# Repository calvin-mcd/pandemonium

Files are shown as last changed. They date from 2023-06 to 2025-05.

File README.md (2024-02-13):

# Pandemonium
 
Pandemonium is an alpha staggered ISO pcb with KLE by HaiZeus. It uses an [XIAO nRF52840](https://www.seeedstudio.com/Seeed-XIAO-BLE-nRF52840-p-5201.html) for bluetooth support. The desgin for that is based on [NoahK#1290's](https://kiserdesigns.bigcartel.com/) [Asymptote](https://github.com/KiserDesigns/Asymptote). For a build guide you can mostly refer to the steps from the [Asymptote Guide](https://github.com/KiserDesigns/Asymptote#asymptote-build-guide). Just take extra care with the right orientation of the diodes, as these change quite a bit on this pcb design. The battery cutout is 54mm x 14mm (max width for batteries used is 14mm).

## Layout

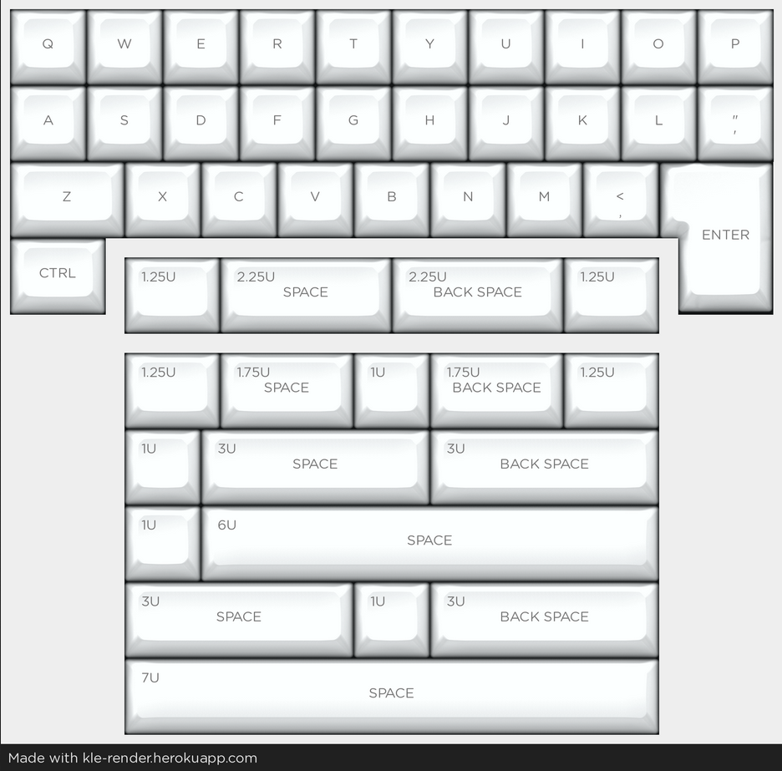
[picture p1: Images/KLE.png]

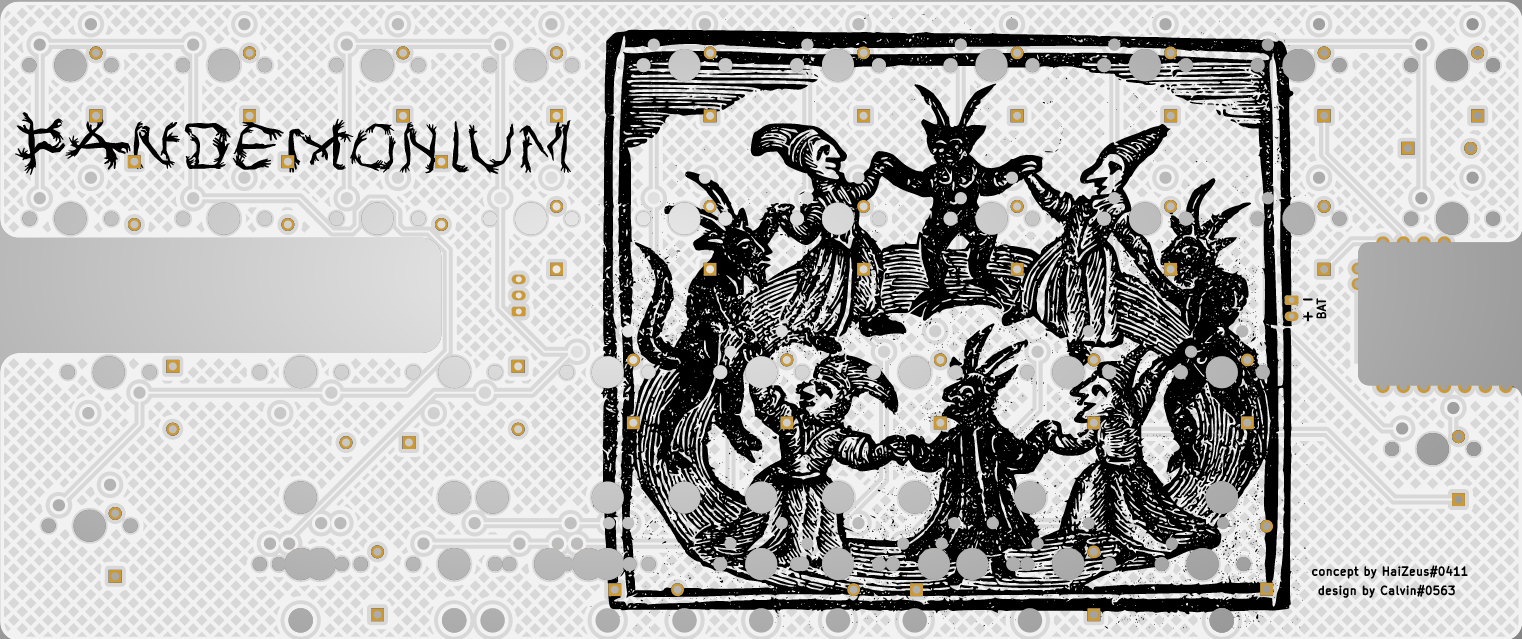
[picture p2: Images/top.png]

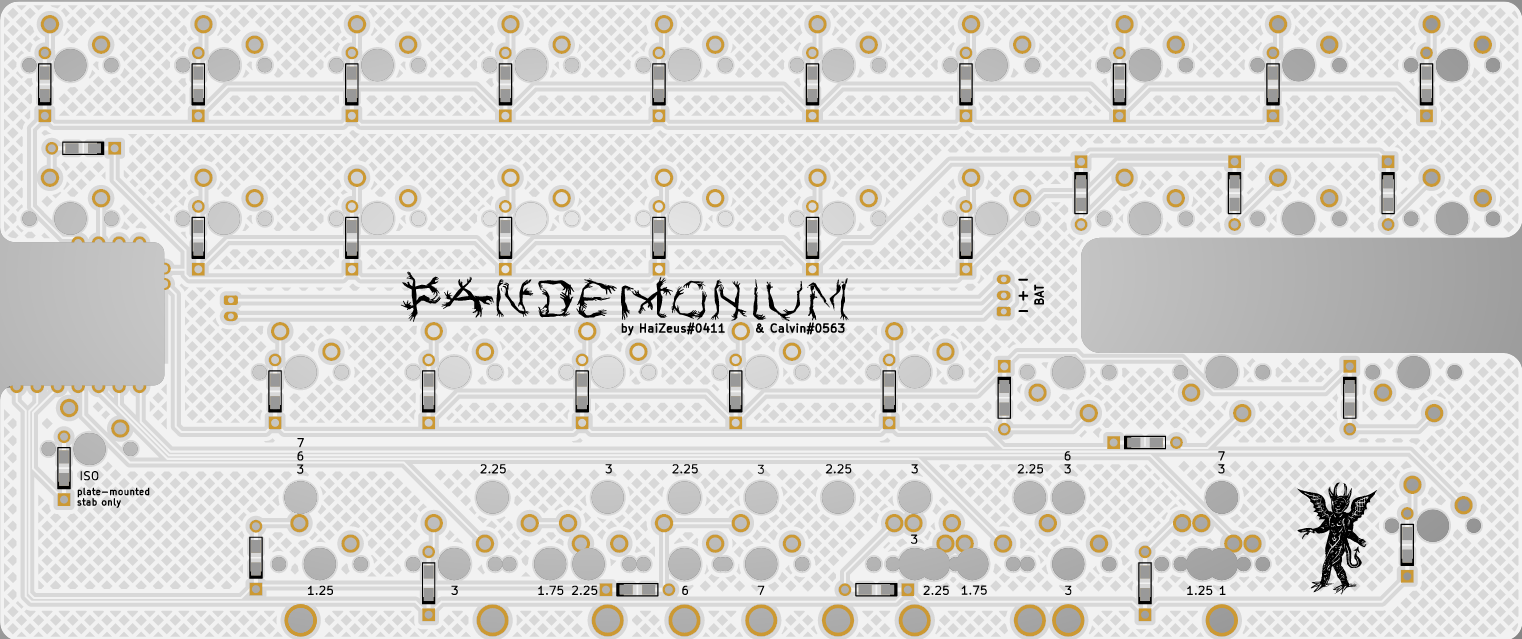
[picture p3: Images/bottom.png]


[Link](http://www.keyboard-layout-editor.com/#/gists/b0a595a186fab9d96212efed305105f0)

## Cases

1) HaiZeus designed the case to be either used for resin or FDM printing. Use the respective top file for that. 

A universal plate file is included as well as two thick plate options for different bottomrow layouts.  

Hardware needed to assemble the cases is:
- 8x M3x4mm heat set inserts or 8x M3 square nuts (depending on case top printing method) (see reference picture below for the kind of square nuts)
- 8x M3x6mm screws

The bottom has cutouts for SKUF rubber feet available at a couple different online retailers.
  
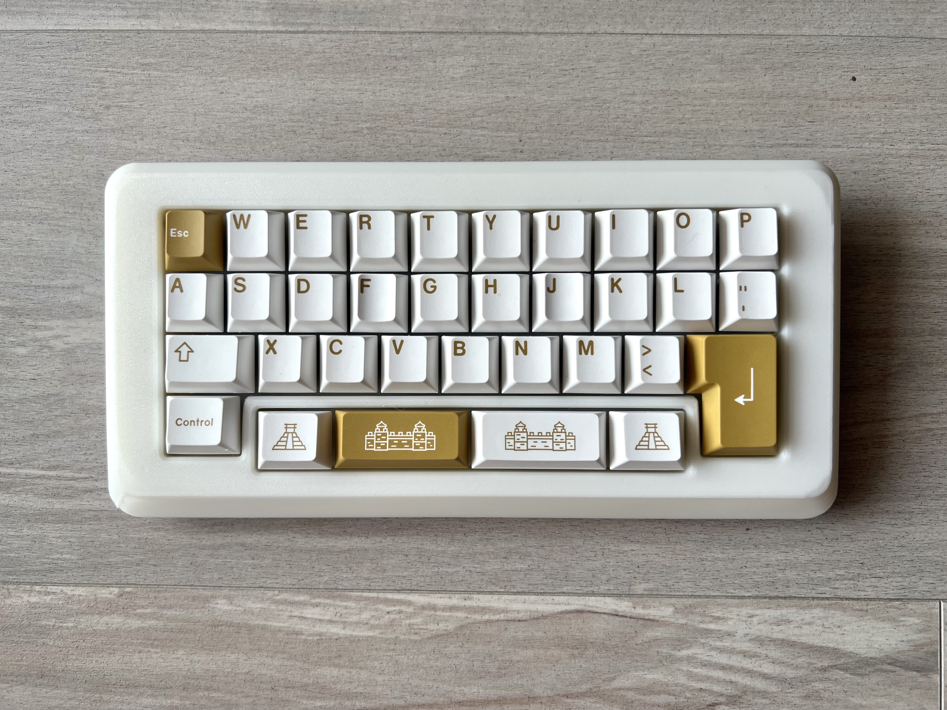
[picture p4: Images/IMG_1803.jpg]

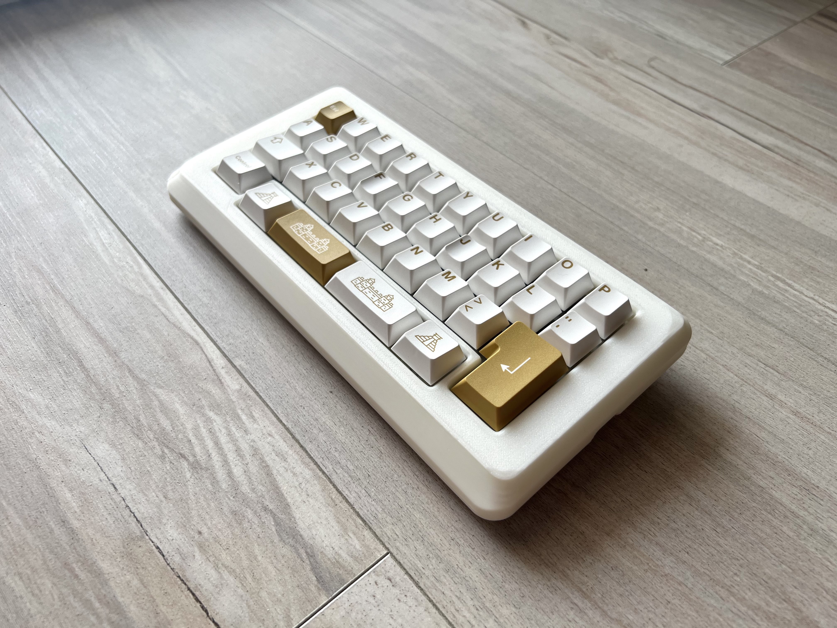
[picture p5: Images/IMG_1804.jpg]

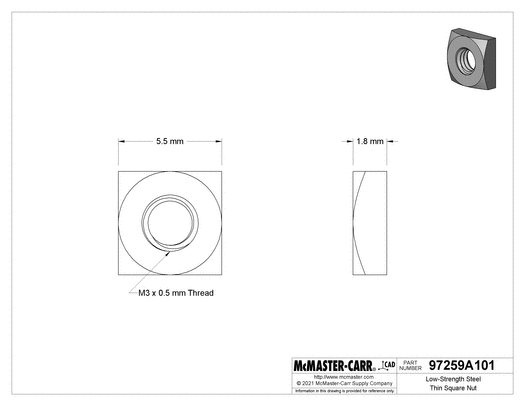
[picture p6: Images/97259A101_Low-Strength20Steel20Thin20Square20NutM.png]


2) There is now also a Hull Style Case made by Ty-Fitz for the OG pandenonium pcb.
https://github.com/Ty-Fitz/Pandi-hull

## Firmware

Firmware has been created in zmk by Falconloft. A basic layout to flash the pcb has been provided. The source code is there to edit and create personal layouts for the board.

## Todo

- [X] order & test pcb
- [X] print & test case
- [X] create ZMK firmware

## Disclaimer

This PCB has been fully tested and confirmed to work. The members of the PCB development team are however not liable if you end up with a non-functional pcb. Order at your own risk. Support will not be provided but pull requests will be reviewed and possibly accepted.

## License

This project is released under the GPL v3 License. Please refer to the LICENCE file.

## Credits

Thanks to HaiZeus for the inspiration, KLE and case design.

Many thanks to Falconloft for his work and patience with the firmware.

Big, big thanks to NoahK#1290 for the design inspiration and support. Do check out Noah's work. It is amazing!

And, as always big thanks to the 40s community!

Any questions, contact calvin0563 on Discord.

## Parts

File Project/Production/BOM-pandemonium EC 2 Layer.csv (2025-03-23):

Comment | Designator | Footprint | LCSC | Quantity
1k | R14 | R_0402_1005Metric | C11702 | 1
ASMD1206-150 | F3 | Fuse_1206_3216Metric | C135341 | 1
220pF NP0 | C30 | C_0402_1005Metric | C1530 | 1
10uF | C37 | C_0603_1608Metric | C1691 | 1
100 | R1,R2,R3,R4 | R_0402_1005Metric | C25076 | 4
10k | R20 | R_0402_1005Metric | C25531 | 1
100k | R13,R16,R17,R18,R19,R21,R24,R25,R26,R27,R28 | R_0402_1005Metric | C25741 | 11
5.1k | R29,R30 | R_0402_1005Metric | C25941 | 2
PRTR5V0U2X | U11 | SOT-143 | C2827688 | 1
USB_C_Receptacle_USB2.0 | J1 | USB_C_Receptacle_HRO_TYPE-C-31-M-12 | C3001293 | 1
100n | C29,C31,C32,C33,C34,C35,C36,C38,C40,C44 | C_0402_1005Metric | C307331 | 10
OPA354 | U5 | SOT-23-5 | C36384 | 1
1u | C39,C41,C42 | C_0402_1005Metric | C52923 | 3
XC6206PxxxMR-Regulator_Linear | U9 | SOT-23 | C5446 | 1
74HC4051 | U6,U7 | TSSOP16 | C5645 | 2
STM32F072CBT6 | U8 | LQFP-48_7x7mm_P0.5mm | C81720 | 1

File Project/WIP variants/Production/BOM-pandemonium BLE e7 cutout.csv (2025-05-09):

Comment | Designator | Footprint | LCSC | Quantity
RST | SW3 | SW_T1A2QR | C100056 | 1
1k | R10,R11,R12 | R_0402_1005Metric | C11702 | 3
BQ24075 | U7 | VQFN-16-1EP_3x3mm_P0.5mm_EP1.6x1.6mm | C15464 | 1
12p | C10,C9 | C_0402_1005Metric | C1547 | 2
SM04B | J5 | JST_SH_SM04B-SRSS-TB_1x04-1MP_P1.00mm_Horizontal | C160404 | 1
750 mA | F2 | Fuse_1206_3216Metric | C20792 | 1
4u7 | C12,C13,C15,C18,C7,C8 | C_0402_1005Metric | C23733 | 6
100R | R3 | R_0402_1005Metric | C25076 | 1
100K | R4 | R_0402_1005Metric | C25530 | 1
10k | R1,R13,R2,R8 | R_0402_1005Metric | C25744 | 4
47k | R14 | R_0402_1005Metric | C25792 | 1
1k5 | R15 | R_0402_1005Metric | C25867 | 1
2k2 | R16 | R_0402_1005Metric | C25879 | 1
MAX17048 | U6 | DFN-8-1EP_2x2mm_P0.5mm_EP0.8x1.6mm | C2682616 | 1
IND | LED1 | LED_1206R | C2802677 | 1
100n | C17 | C_0402_1005Metric | C307331 | 1
nRF52840_E73-2G4M08S1C | U1 | nRF52840_E73-2G4M08S1C | C356849 | 1
SW_SPDT | SW4 | SW_MSK12C02-HB | C431540 | 1
78171-0002 | J3 | Molex_Pico-EZmate_78171-0002_1x02-1MP_P1.20mm_Vertical | C505023 | 1
1u | C14,C16,C19,C6 | C_0402_1005Metric | C52923 | 4
32.768 KHz | Y1 | Crystal_SMD_2012-2Pin_2.0x1.2mm | C55208 | 1
D_Small | D1,D10,D11,D12,D13,D14,D15,D16,D17,D18,D19,D2,D20,D21,D22,D23,D24,D25,D26,D27,D28,D29,D3,D30,D31,D32,D34,D35,D37,D4,D40,D5,D6,D7,D8,D9 | D_SOD-123F | C81598 | 36
2N7002 | Q1 | SOT-23 | C8545 | 1
BLM15PX121SN1D | L2 | L_0402_1005Metric | C88970 | 1
10 uH | L1 | L_0603_1608Metric | C92982 | 1

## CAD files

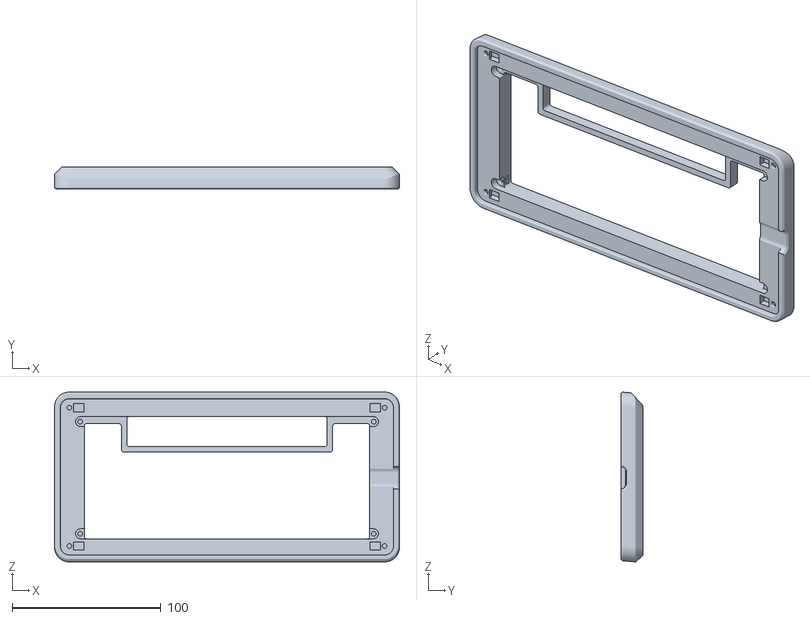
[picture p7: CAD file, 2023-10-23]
Case/PandemoniumCaptiveNutTopResinPrint.stl
231.5 x 15.0 x 114.0

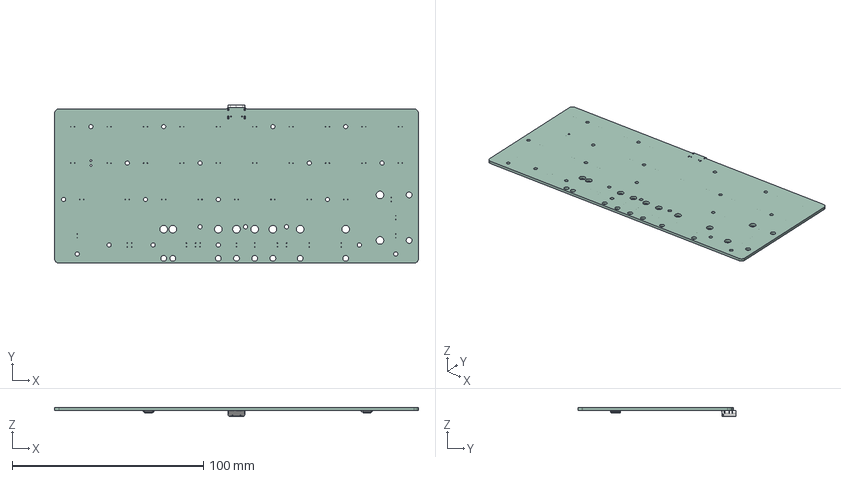
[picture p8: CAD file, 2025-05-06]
Project/WIP variants/EC variant/pandemonium EC.step
190.5 x 82.9 x 4.80 mm
CON_TYPE-C-31-M-12 v0
SSOP_16_44x52mm_P065mm x 2
pandemonium EC 2 Layer_PCB

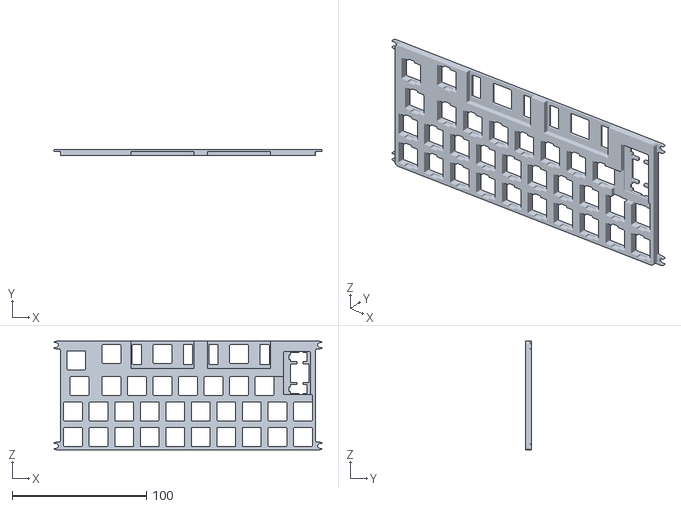
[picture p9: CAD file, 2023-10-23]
Case/Pandemonium1u_3u_3uThickPlate.stl
199.9 x 4.76 x 81.0

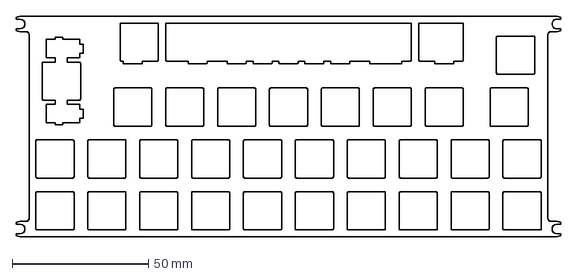
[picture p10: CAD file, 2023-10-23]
Case/PandemoniumUniversalPlate.dxf
200.0 x 81.0 mm

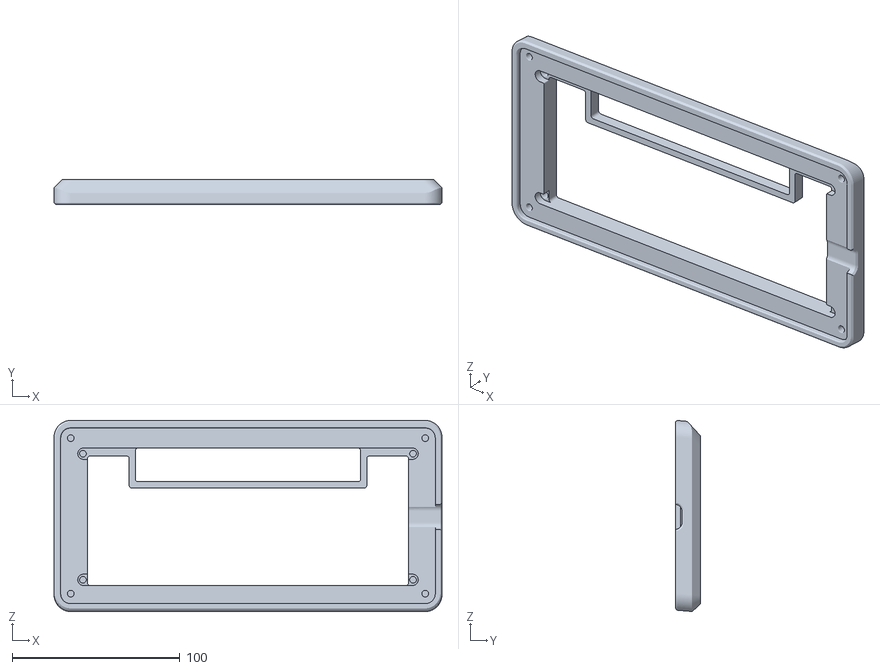
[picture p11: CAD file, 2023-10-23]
Case/PandemoniumHeatSetTopFDMPrint.stl
231.5 x 15.0 x 114.0

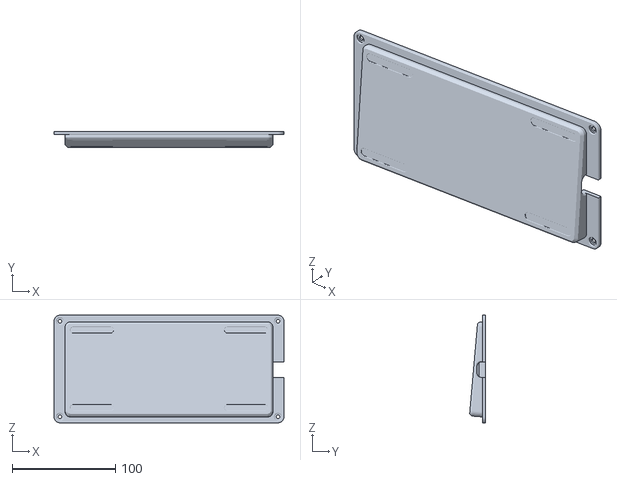
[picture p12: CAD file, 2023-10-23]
Case/PandemoniumBottom.stl
223.1 x 15.3 x 104.4

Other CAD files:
Case/Pandemonium2x2.25uThickPlate.stl

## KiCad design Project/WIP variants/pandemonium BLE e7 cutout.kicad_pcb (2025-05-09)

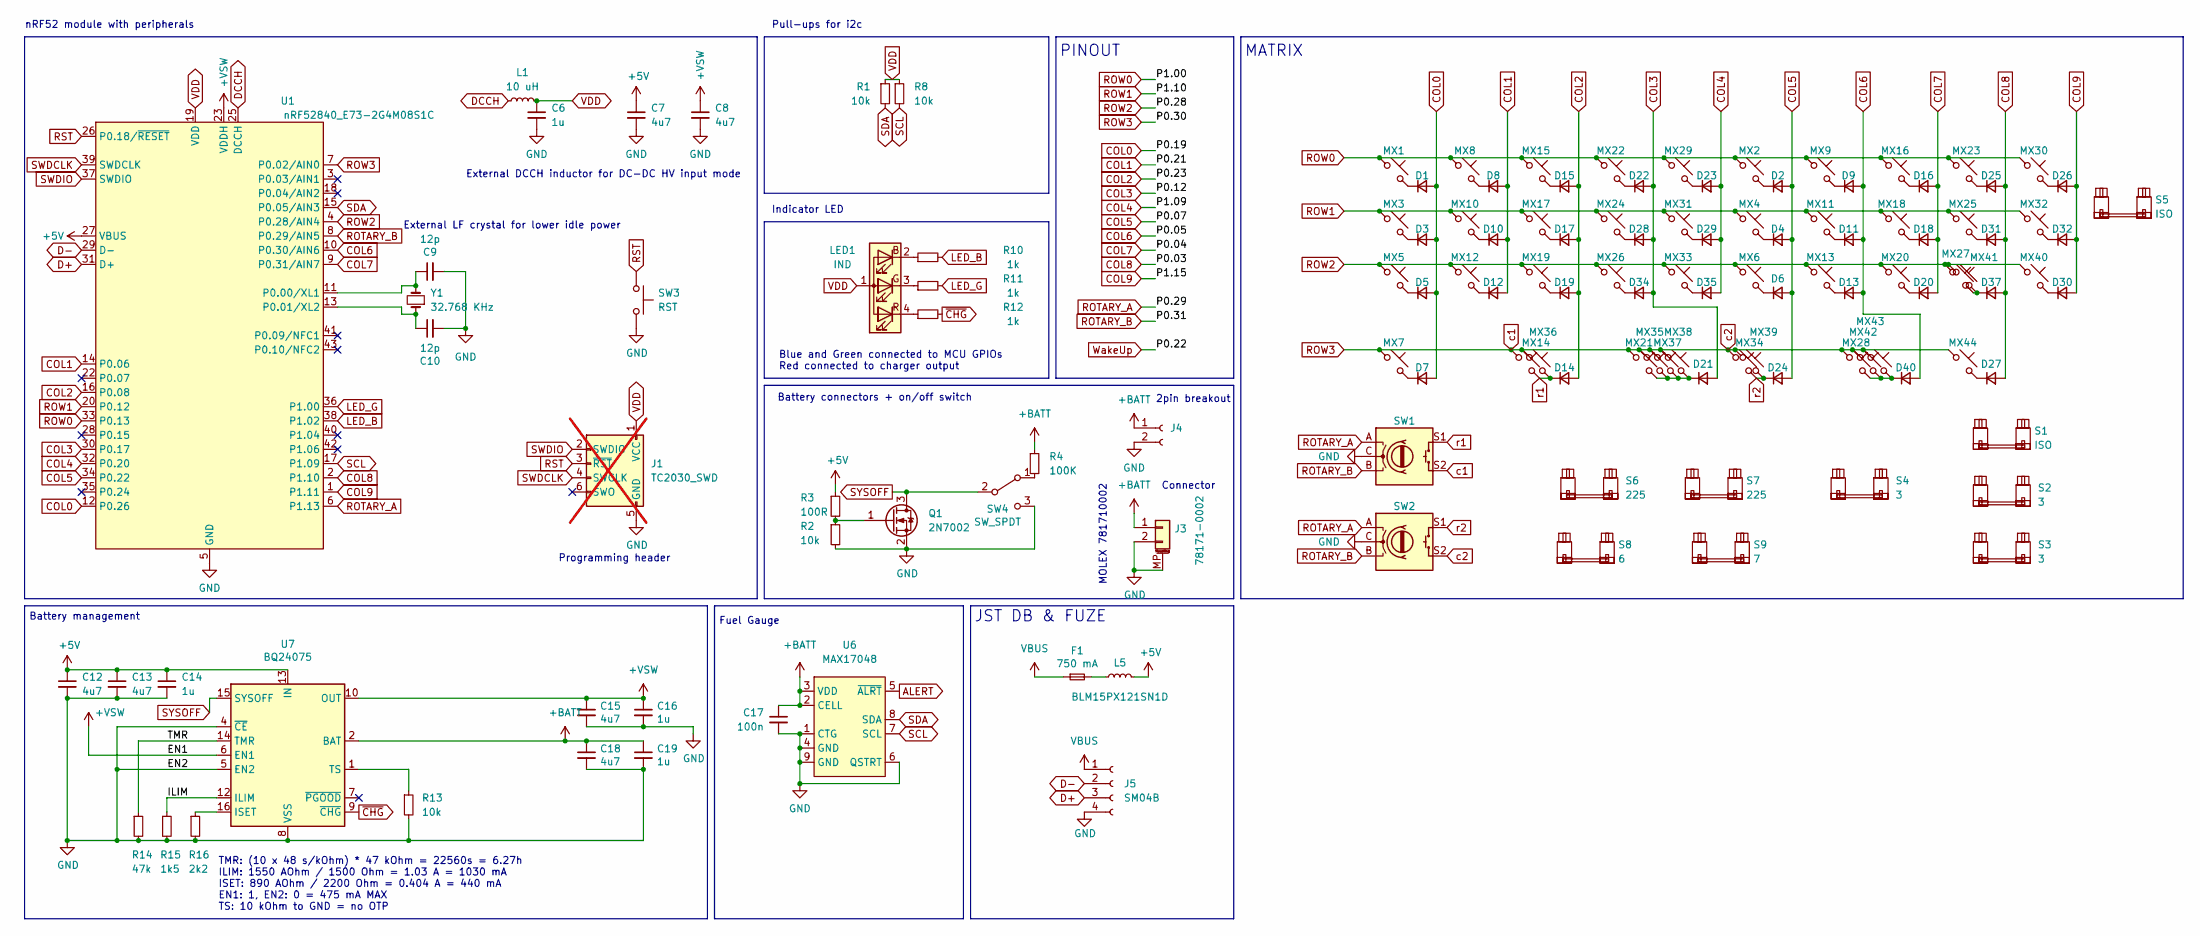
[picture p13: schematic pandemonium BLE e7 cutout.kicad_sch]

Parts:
C6, C14, C16, C19: 1u; C_0402_1005Metric; LCSC C52923
C7, C8, C12, C13, C15, C18: 4u7; C_0402_1005Metric; LCSC C23733
C9, C10: 12p; C_0402_1005Metric; LCSC C1547
C17: 100n; C_0402_1005Metric; LCSC C307331
D1, D2, D3, D4, D5, D6, D7, D8, D9, D10, D11, D12, D13, D14, D15, D16, D17, D18, D19, D20, D21, D22, D23, D24, D25, D26, D27, D28, D29, D30, D31, D32, D34, D35, D37, D40: D_Small; D_SOD-123F
F1: 750 mA; Fuse_1206_3216Metric; LCSC C20792
J1: TC2030_SWD; CON_TC2030_outlined; not fitted
J3: 78171-0002; Molex_Pico-EZmate_78171-0002_1x02-1MP_P1.20mm_Vertical; LCSC C505023
J4: Conn_01x02_Female; JST_PH_S2B-PH-K_1x02_P2.00mm_Horizontal
J5: SM04B; JST_SH_SM04B-SRSS-TB_1x04-1MP_P1.00mm_Horizontal
L1: 10 uH; L_0603_1608Metric; LCSC C92982
L5: BLM15PX121SN1D; L_0402_1005Metric; LCSC C88970
LED1: IND; LED_1206R; LCSC C2802677
MX1, MX2, MX3, MX4, MX6, MX8, MX9, MX10, MX11, MX12, MX13, MX14, MX15, MX16, MX17, MX18, MX19, MX20, MX21, MX22, MX23, MX24, MX25, MX26, MX27, MX28, MX29, MX30, MX31, MX32, MX33, MX34, MX35, MX37, MX39, MX42: MX_SW_solder; SW_MX_1u
MX5, MX41: MX_SW_solder; SW_MX_1.5u
MX7, MX36, MX40, MX44: MX_SW_solder; SW_MX_1.25u
MX38, MX43: MX_SW_solder; SW_MX_1.75u
Q1: 2N7002; SOT-23
R1, R8, R13: 10k; R_0402_1005Metric; LCSC C25744
R2: 10k; R_0402_1005Metric
R3: 100R; R_0402_1005Metric
R4: 100K; R_0402_1005Metric
R10, R11, R12: 1k; R_0402_1005Metric; LCSC C11702
R14: 47k; R_0402_1005Metric; LCSC C25792
R15: 1k5; R_0402_1005Metric; LCSC C25867
R16: 2k2; R_0402_1005Metric; LCSC C25879
S1: ISO; STAB_MX_P_ISO
S2, S3, S4: 3; STAB_MX_P_3u
S5: ISO; STAB_MX_P_ISO-ROT
S6, S7: 225; STAB_MX_P_2.25u
S8: 6; STAB_MX_P_6u
S9: 7; STAB_MX_P_7u
SW1, SW2: RotaryEncoder_Switch; ROT_Alps_EC11E-Switch
SW3: RST; SW_T1A2QR; LCSC C100056
SW4: SW_SPDT; SW_MSK12C02-HB
U1: nRF52840_E73-2G4M08S1C; LCSC C356849
U6: MAX17048; DFN-8-1EP_2x2mm_P0.5mm_EP0.8x1.6mm; LCSC C2682616
U7: BQ24075; VQFN-16-1EP_3x3mm_P0.5mm_EP1.6x1.6mm; LCSC C15464
Y1: 32.768 KHz; Crystal_SMD_2012-2Pin_2.0x1.2mm; LCSC C55208

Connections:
+5V: C7.1, C12.1, C13.1, C14.1, R3.1, U1.27 (VBUS), U7.13 (IN); also elsewhere on the board
+BATT: C17.1, C18.1, C19.1, J3.1, J4.1, R4.1, U6.2 (CELL), U6.3 (VDD), U7.2 (BAT), U7.3 (BAT)
+VSW: C8.1, C15.1, C16.1, U1.23 (VDDH), U7.6 (EN1), U7.10 (OUT), U7.11 (OUT)
/ILIM: R15.1, U7.12 (ILIM)
/TMR: R14.1, U7.14 (TMR)
ALERT: U6.5 (~ALRT)
COL0: D1.2 (A), D3.2 (A), D5.2 (A), D7.2 (A), U1.12 (P0.26)
COL1: D8.2 (A), D10.2 (A), D12.2 (A), U1.14 (P0.06)
COL2: D14.2 (A), D15.2 (A), D17.2 (A), D19.2 (A), U1.16 (P0.08)
COL3: D21.2 (A), D22.2 (A), D28.2 (A), D34.2 (A), U1.30 (P0.17)
COL4: D23.2 (A), D29.2 (A), D35.2 (A), U1.32 (P0.20)
COL5: D2.2 (A), D4.2 (A), D6.2 (A), D24.2 (A), U1.34 (P0.22)
COL6: D9.2 (A), D11.2 (A), D13.2 (A), D40.2 (A), U1.10 (P0.30/AIN6)
COL7: D16.2 (A), D18.2 (A), D20.2 (A), U1.9 (P0.31/AIN7)
COL8: D25.2 (A), D27.2 (A), D31.2 (A), D37.2 (A), U1.2 (P1.10)
COL9: D26.2 (A), D30.2 (A), D32.2 (A), U1.1 (P1.11)
D+: J5.3, U1.31 (D+)
D-: J5.2, U1.29 (D-)
DCCH: L1.1, U1.25 (DCCH)
GND: C6.2, C7.2, C8.2, C9.2, C10.2, C12.2, C13.2, C14.2, C15.2, C16.2, C17.2, C18.2, C19.2, J1.5 (GND), J3.2, J3.MP (MountPin), J4.2, J5.4, Q1.2 (S), R2.2, R13.2, R14.2, R15.2, R16.2, SW1.C, SW2.C, SW3.2, SW4.3 (C), U1.5 (GND), U1.21 (GND), U1.24 (GND), U6.1 (CTG), U6.4 (GND), U6.6 (QSTRT), U6.9 (GND), U7.4 (~CE), U7.5 (EN2), U7.8 (VSS), U7.17 (VSS)
LED_B: R10.2, U1.38 (P1.02)
LED_G: R11.2, U1.36 (P1.00)
unnamed: D1.1 (K), MX1.2
unnamed: D2.1 (K), MX2.2
unnamed: D3.1 (K), MX3.2
unnamed: D4.1 (K), MX4.2
unnamed: D5.1 (K), MX5.2
unnamed: D6.1 (K), MX6.2
unnamed: D7.1 (K), MX7.2
unnamed: D8.1 (K), MX8.2
unnamed: D9.1 (K), MX9.2
unnamed: D10.1 (K), MX10.2
unnamed: D11.1 (K), MX11.2
unnamed: D12.1 (K), MX12.2
unnamed: D13.1 (K), MX13.2
unnamed: D15.1 (K), MX15.2
unnamed: D16.1 (K), MX16.2
unnamed: D17.1 (K), MX17.2
unnamed: D18.1 (K), MX18.2
unnamed: D19.1 (K), MX19.2
unnamed: D20.1 (K), MX20.2
unnamed: D21.1 (K), MX21.2, MX35.2, MX37.2, MX38.2
unnamed: D22.1 (K), MX22.2
unnamed: D23.1 (K), MX29.2
unnamed: D25.1 (K), MX23.2
unnamed: D26.1 (K), MX30.2
unnamed: D27.1 (K), MX44.2
unnamed: D28.1 (K), MX24.2
unnamed: D29.1 (K), MX31.2
unnamed: D30.1 (K), MX40.2
unnamed: D31.1 (K), MX25.2
unnamed: D32.1 (K), MX32.2
unnamed: D34.1 (K), MX26.2
unnamed: D35.1 (K), MX33.2
unnamed: D37.1 (K), MX27.2, MX41.2
unnamed: D40.1 (K), MX28.2, MX42.2, MX43.2
unnamed: LED1.2 (BK), R10.1
unnamed: LED1.3 (GK), R11.1
unnamed: LED1.4 (RK), R12.1
unnamed: Q1.1 (G), R2.1, R3.2
unnamed: R4.2, SW4.1 (A)
unnamed: C9.1, U1.11 (P0.00/XL1), Y1.2
unnamed: C10.1, U1.13 (P0.01/XL2), Y1.1
unnamed: R16.1, U7.16 (ISET)
unnamed: R13.1, U7.1 (TS)
ROTARY_A: SW1.A, SW2.A, U1.6 (P1.13)
ROTARY_B: SW1.B, SW2.B, U1.8 (P0.29/AIN5)
ROW0: MX1.1, MX2.1, MX8.1, MX9.1, MX15.1, MX16.1, MX22.1, MX23.1, MX29.1, MX30.1, U1.33 (P0.13)
ROW1: MX3.1, MX4.1, MX10.1, MX11.1, MX17.1, MX18.1, MX24.1, MX25.1, MX31.1, MX32.1, U1.20 (P0.12)
ROW2: MX5.1, MX6.1, MX12.1, MX13.1, MX19.1, MX20.1, MX26.1, MX27.1, MX33.1, MX40.1, MX41.1, U1.4 (P0.28/AIN4)
ROW3: MX7.1, MX14.1, MX21.1, MX28.1, MX34.1, MX35.1, MX36.1, MX37.1, MX38.1, MX39.1, MX42.1, MX43.1, MX44.1, SW1.S2, SW2.S2, U1.7 (P0.02/AIN0)
RST: J1.3 (~RST), SW3.1, U1.26 (P0.18/~RESET)
SCL: R8.2, U1.17 (P1.09), U6.7 (SCL)
SDA: R1.2, U1.15 (P0.05/AIN3), U6.8 (SDA)
SWDCLK: J1.4 (SWCLK), U1.39 (SWDCLK)
SWDIO: J1.2 (SWDIO), U1.37 (SWDIO)
SYSOFF: Q1.3 (D), SW4.2 (B), U7.15 (SYSOFF)
VBUS: J5.1; also elsewhere on the board
VDD: C6.1, J1.1 (VCC), L1.2, LED1.1 (A), R1.1, R8.1, U1.19 (VDD)
r1: D14.1 (K), MX14.2, MX36.2, SW1.S1
r2: D24.1 (K), MX34.2, MX39.2, SW2.S1
~CHG: R12.2, U7.9 (~CHG)

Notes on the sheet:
Programming header
Pull-ups for i2c
Indicator LED
Blue and Green connected to MCU GPIOs Red connected to charger output
MOLEX 781710002
nRF52 module with peripherals
Connector
TMR: (10 x 48 s/kOhm) * 47 kOhm = 22560s = 6.27h ILIM: 1550 AOhm / 1500 Ohm = 1.03 A = 1030 mA ISET: 890 AOhm / 2200 Ohm = 0.404 A = 440 mA EN1: 1, EN2: 0 = 475 mA MAX TS: 10 kOhm to GND = no OTP
Battery management
PINOUT
Battery connectors + on/off switch
MATRIX
External LF crystal for lower idle power
External DCCH inductor for DC-DC HV input mode
JST DB & FUZE
2pin breakout
Fuel Gauge

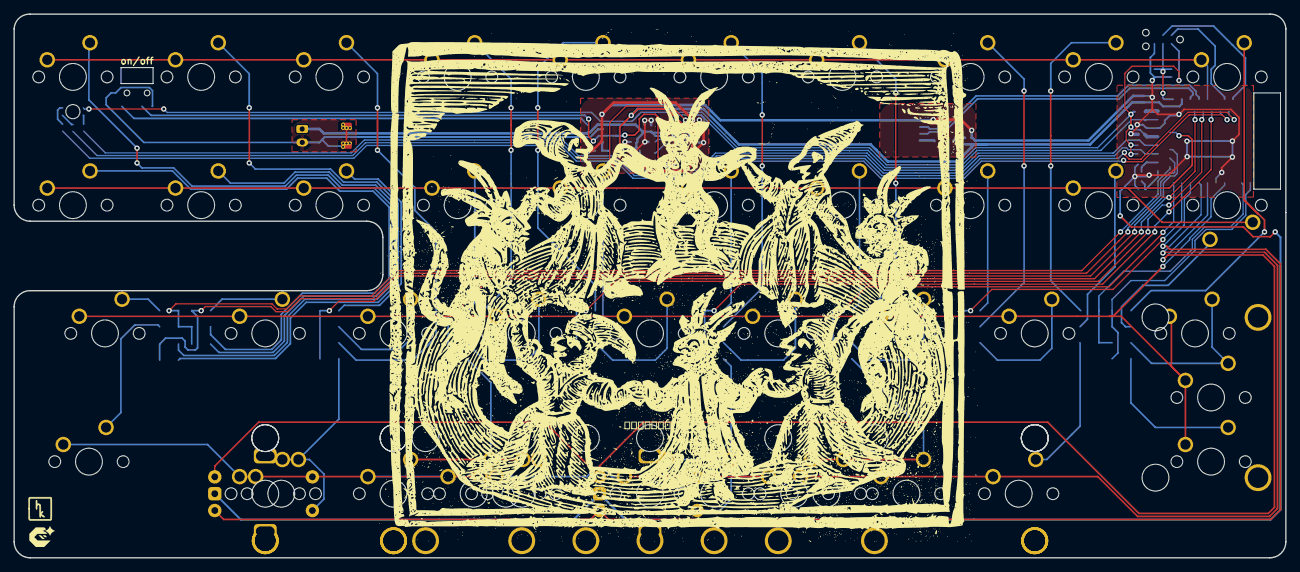
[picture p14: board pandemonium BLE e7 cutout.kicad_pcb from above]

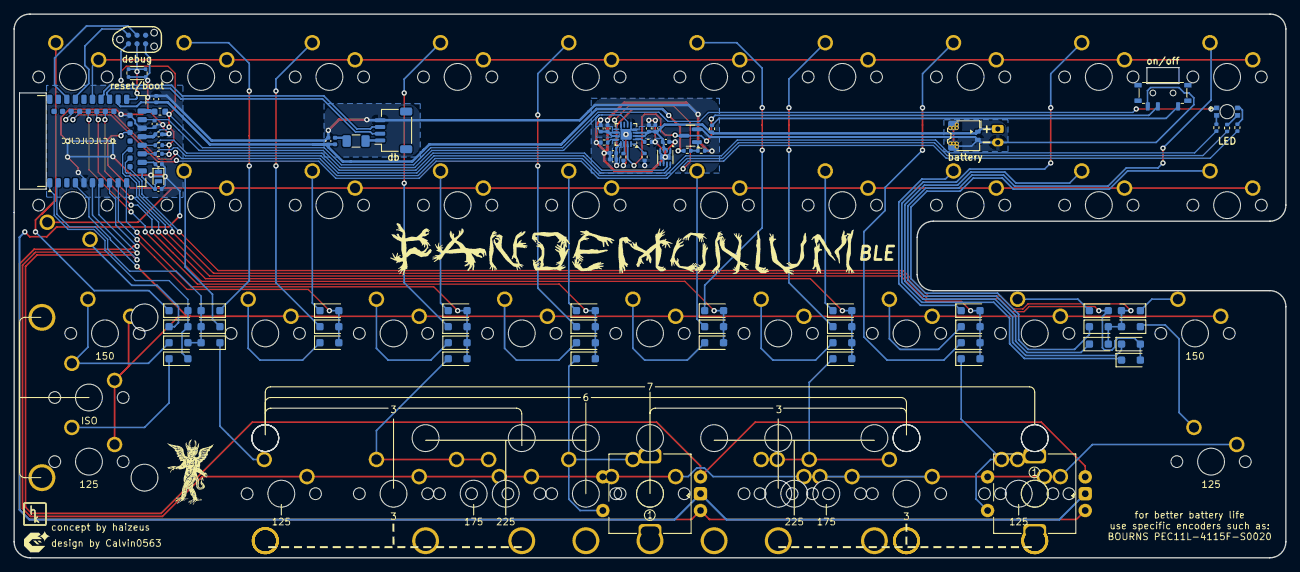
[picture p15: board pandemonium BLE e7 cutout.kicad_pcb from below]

Board: 2 copper layers, 188.9 x 80.8 mm, 130 parts (76 on the bottom side), 82 nets.

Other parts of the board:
F2: 750 mA; Fuse_1206_3216Metric
L2: BLM15PX121SN1D; L_0402_1005Metric

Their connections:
+5V: L2.2; also elsewhere on the board
unnamed: F2.2, L2.1
VBUS: F2.1; also elsewhere on the board

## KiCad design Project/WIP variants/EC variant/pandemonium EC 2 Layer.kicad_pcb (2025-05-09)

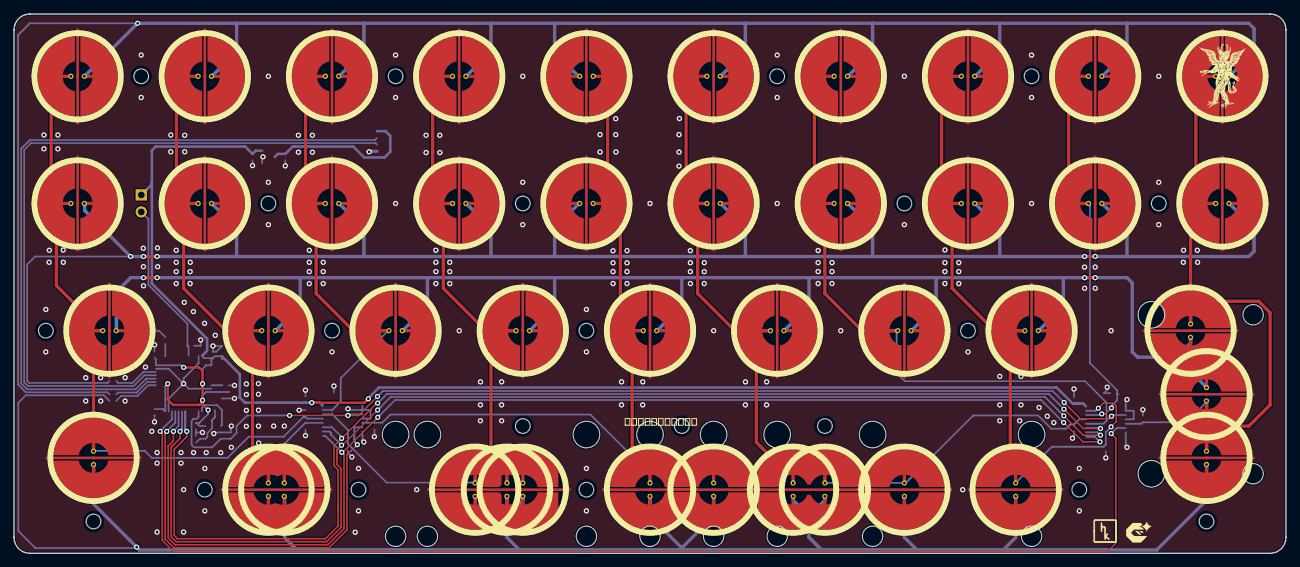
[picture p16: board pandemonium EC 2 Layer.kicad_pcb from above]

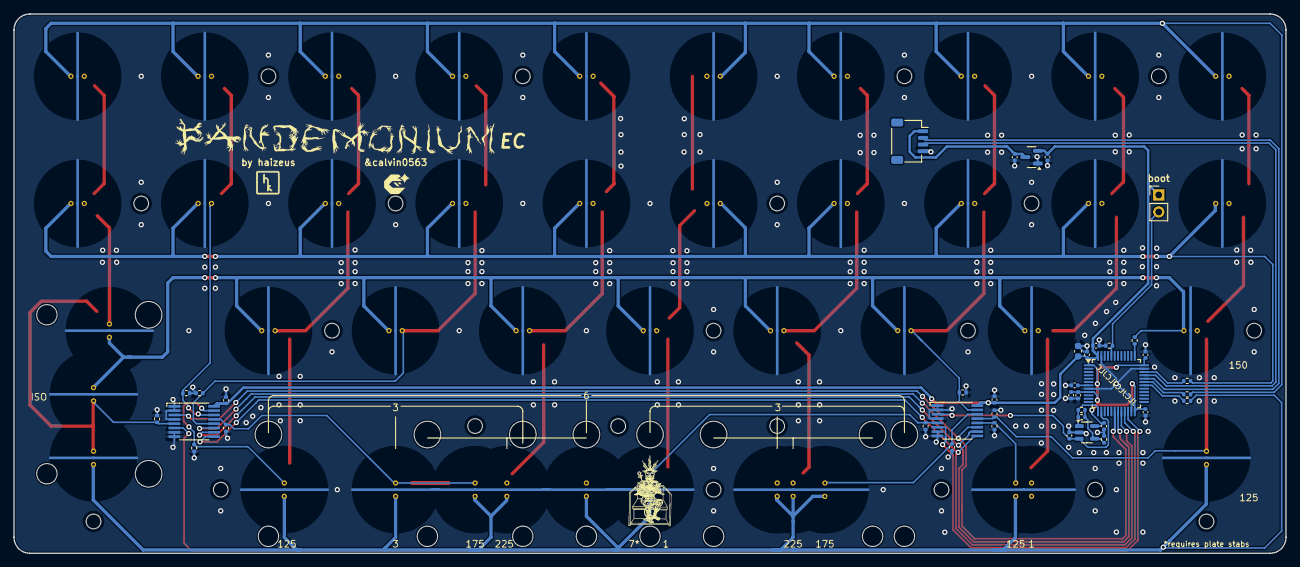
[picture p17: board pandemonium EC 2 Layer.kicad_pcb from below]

Board: 2 copper layers, 190.5 x 80.8 mm, 104 parts (39 on the bottom side), 33 nets.

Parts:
C29, C31, C32, C38: 100n; C_0402_1005Metric
C30: 220pF NP0; C_0402_1005Metric
C33, C34, C35, C36, C40: 100nF; C_0402_1005Metric
C37: 10uF; C_0603_1608Metric
C39: 1u; C_0402_1005Metric
C41, C42: 1uF; C_0402_1005Metric
H1, H2, H3, H4, H5, H6, H7, H8, H9, H10, H11, H12, H14, H15, H16, H17, H18, H19, H20, H23, H24: MountingHole; HOLE_M2 (no arrow)
J2: SM04B; JST_SH_SM04B-SRSS-TB_1x04-1MP_P1.00mm_Horizontal
R1, R2, R3, R4: 100; R_0402_1005Metric
R13, R16, R17, R18, R19, R21, R24, R25, R26, R27, R28: 100k; R_0402_1005Metric
R14: 1k; R_0402_1005Metric
R15: DNP; R_0402_1005Metric
R20: 10k; R_0402_1005Metric
S1, S2: 225; STAB_MX_2.25u
S3: 225; STAB_MX_ISO-ROT
S4, S5: 3; STAB_MX_3u
SW1: DFU; PinHeader_1x02_P2.54mm_Vertical
SW_EC1, SW_EC2, SW_EC3, SW_EC4, SW_EC5, SW_EC6, SW_EC7, SW_EC8, SW_EC9, SW_EC10, SW_EC11, SW_EC12, SW_EC13, SW_EC14, SW_EC15, SW_EC16, SW_EC17, SW_EC18, SW_EC19, SW_EC20, SW_EC21, SW_EC22, SW_EC23, SW_EC24, SW_EC25, SW_EC26, SW_EC27, SW_EC28, SW_EC29, SW_EC30, SW_EC31, SW_EC35, SW_EC38, SW_EC39, SW_EC40: Topre; ecs_pad_1U_no_ring
SW_EC32: Topre; ecs_pad_no_ring_1u&1.25u&1.5u
SW_EC33: Topre; ecs_pad_0.25U_0.125U_spaced_no_ring_cut_right
SW_EC34: Topre; ecs_pad_1U_no_ring_1u_edge_cut_horizontal
SW_EC36: Topre; ecs_pad_no_ring_stepped&normal_cut
U5: OPA354; SOT-23-5
U6, U7: 74HC4051; TSSOP16
U8: STM32F072CBT6; LQFP-48_7x7mm_P0.5mm
U9: XC6206PxxxMR-Regulator_Linear; SOT-23

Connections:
+3V3: C29.2, C31.2, C32.2, C33.1, C34.1, C35.1, C36.1, C37.1, C38.1, C39.1, C42.2, SW1.1, U5.5 (V+), U6.16 (VCC), U7.16 (VCC), U8.1 (VBAT), U8.9 (VDDA), U8.24 (VDD), U8.36 (VDDIO2), U8.48 (VDD), U9.2 (VO)
+5V: C41.2, J2.1, U9.3 (VI)
ADC: R13.1, R15.1, U5.1, U8.13 (PA3)
AMUX_SEL_0: U6.11 (S0), U7.11 (S0), U8.18 (PB0)
AMUX_SEL_1: U6.10 (S1), U7.10 (S1), U8.19 (PB1)
AMUX_SEL_2: U6.9 (S2), U7.9 (S2), U8.20 (PB2)
APLEX_EN_PIN_0: U6.6 (~E), U8.21 (PB10)
APLEX_EN_PIN_1: U7.6 (~E), U8.22 (PB11)
APLEX_OUT: C30.1, U5.3 (+), U6.3 (A), U7.3 (A), U8.14 (PA4)
BOOT0: R20.1, SW1.2, U8.44 (BOOT0)
COL0: R16.1, SW_EC1.1, SW_EC11.1, SW_EC21.1, SW_EC31.1, U6.13 (A0)
COL1: R19.1, SW_EC2.1, SW_EC12.1, SW_EC22.1, SW_EC32.1, U6.12 (A3)
COL2: R18.1, SW_EC3.1, SW_EC13.1, SW_EC23.1, U6.15 (A2)
COL3: R17.1, SW_EC4.1, SW_EC14.1, SW_EC24.1, SW_EC33.1, U6.14 (A1)
COL4: R21.1, SW_EC5.1, SW_EC15.1, SW_EC25.1, SW_EC34.1, SW_EC35.1, U6.5 (A5)
COL5: R24.1, SW_EC6.1, SW_EC16.1, SW_EC26.1, SW_EC36.1, SW_EC40.1, U7.13 (A0)
COL6: R27.1, SW_EC7.1, SW_EC17.1, SW_EC27.1, U7.12 (A3)
COL7: R26.1, SW_EC8.1, SW_EC18.1, SW_EC28.1, SW_EC38.1, U7.15 (A2)
COL8: R25.1, SW_EC9.1, SW_EC19.1, U7.14 (A1)
COL9: R28.1, SW_EC10.1, SW_EC20.1, SW_EC29.1, SW_EC30.1, SW_EC39.1, U7.5 (A5)
D_N: J2.2, U8.32 (PA11)
D_P: J2.3, U8.33 (PA12)
GND: C29.1, C30.2, C31.1, C32.1, C33.2, C34.2, C35.2, C36.2, C37.2, C38.2, C39.2, C40.2, C41.1, C42.1, J2.4, R14.2, R16.2, R17.2, R18.2, R19.2, R20.2, R21.2, R24.2, R25.2, R26.2, R27.2, R28.2, SW_EC1.3 (SG), SW_EC2.3 (SG), SW_EC3.3 (SG), SW_EC4.3 (SG), SW_EC5.3 (SG), SW_EC6.3 (SG), SW_EC7.3 (SG), SW_EC8.3 (SG), SW_EC9.3 (SG), SW_EC10.3 (SG), SW_EC11.3 (SG), SW_EC12.3 (SG), SW_EC13.3 (SG), SW_EC14.3 (SG), SW_EC15.3 (SG), SW_EC16.3 (SG), SW_EC17.3 (SG), SW_EC18.3 (SG), SW_EC19.3 (SG), SW_EC20.3 (SG), SW_EC21.3 (SG), SW_EC22.3 (SG), SW_EC23.3 (SG), SW_EC24.3 (SG), SW_EC25.3 (SG), SW_EC26.3 (SG), SW_EC27.3 (SG), SW_EC28.3 (SG), SW_EC29.3 (SG), SW_EC30.3 (SG), SW_EC31.3 (SG), SW_EC32.3 (SG), SW_EC33.3 (SG), SW_EC34.3 (SG), SW_EC35.3 (SG), SW_EC36.3 (SG), SW_EC38.3 (SG), SW_EC39.3 (SG), SW_EC40.3 (SG), U5.2 (V-), U6.1 (A4), U6.2 (A6), U6.4 (A7), U6.7 (VEE), U6.8 (GND), U7.1 (A4), U7.2 (A6), U7.4 (A7), U7.7 (VEE), U7.8 (GND), U8.8 (VSSA), U8.23 (VSS), U8.35 (VSS), U8.47 (VSS), U9.1 (GND)
NRST: C40.1, U8.7 (NRST)
unnamed: R13.2, R14.1, R15.2, U5.4 (-)
unnamed: R4.1, U8.30 (PA9)
unnamed: R1.1, U8.31 (PA10)
unnamed: R2.1, U8.34 (PA13)
unnamed: R3.1, U8.37 (PA14)
ROW0: R1.2, SW_EC1.2, SW_EC2.2, SW_EC3.2, SW_EC4.2, SW_EC5.2, SW_EC6.2, SW_EC7.2, SW_EC8.2, SW_EC9.2, SW_EC10.2
ROW1: R2.2, SW_EC11.2, SW_EC12.2, SW_EC13.2, SW_EC14.2, SW_EC15.2, SW_EC16.2, SW_EC17.2, SW_EC18.2, SW_EC19.2, SW_EC20.2
ROW2: R3.2, SW_EC21.2, SW_EC22.2, SW_EC23.2, SW_EC24.2, SW_EC25.2, SW_EC26.2, SW_EC27.2, SW_EC28.2, SW_EC29.2, SW_EC30.2
ROW3: R4.2, SW_EC31.2, SW_EC32.2, SW_EC33.2, SW_EC34.2, SW_EC35.2, SW_EC36.2, SW_EC38.2, SW_EC39.2, SW_EC40.2

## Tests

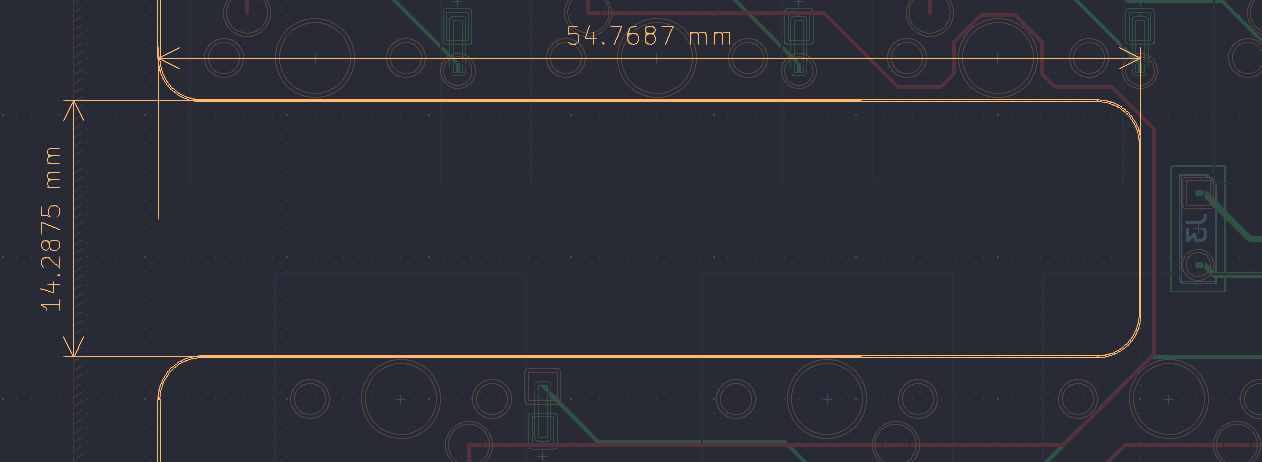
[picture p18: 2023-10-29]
Images/battery measurements.png

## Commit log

2023-07-10 step file, gerber files created
    [pandemonium-B_Cu.gbr, pandemonium-B_Mask.gbr, pandemonium-B_Paste.gbr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]
2023-08-20 added images of Haizeus' case design
2023-10-23 added latest case file, firmware files, updated readme
    [Pandemonium1-3-3SwitchPlate.stl, Pandemonium1u_3u_3uThickPlate.stl, Pandemonium2x2.25uPlate.stl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]
2023-10-29 updated readme with battery info
2023-11-09 BLE progress
    [Battey Management.kicad_sch, USB.kicad_sch, pandemonium BLE.kicad_sch]
2023-11-17 EC version finished
    [USB EC.kicad_sch, analog.kicad_sch, matrix.kicad_sch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]
2023-12-02 separeted EC project from the OG and BLE-wip
    [USB EC.kicad_sch, analog.kicad_sch, matrix.kicad_sch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]
2024-01-04 small work on pandi EC and BLE
    [pandemonium BLE.kicad_sch, pandemonium EC 2 Layer.kicad_pcb]
2024-01-09 switching to holyiot for BLE
    [USB.kicad_sch, pandemonium BLE.kicad_sch]
2024-01-19 EC plates created
    [pandemonium BLE.kicad_sch, pandemonium EC 2 Layer.kicad_pcb, pandemonium EC.kicad_pcb]
2024-02-09 BLE version close to proto run
    implement john's last suggestions
    [Battey Management.kicad_sch, USB.kicad_sch, pandemonium BLE.kicad_sch]
2024-02-11 changes to topre version and BLE version
    [mounting holes.kicad_sch, pandemonium BLE.kicad_sch, pandemonium EC 175u ISO plate.kicad_pcb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]
2024-02-13 update readme with hull case
2024-02-27 fresh gerbers, easier THT labelling
    [pandemonium-B_Cu.gbr, pandemonium-B_Mask.gbr, pandemonium-B_Paste.gbr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]
2024-02-27 fresh gerbers
2024-03-30 project cleanup, WIP folder
    [USB EC.kicad_sch, analog.kicad_sch, matrix.kicad_sch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]
2024-09-16 e73 version work
    [pandemonium BLE e7.kicad_sch, pandemonium BLE.kicad_sch]
2024-12-24 integrated wip
    [pandemonium BLE e7.kicad_sch]
2025-01-24 battery charging sysoff added
    [pandemonium BLE e7 cutout.kicad_sch]
2025-03-01 ble integrated wip
    [pandemonium BLE e7 cutout.kicad_pcb]
2025-03-23 production files EC
    [BOM-pandemonium EC 2 Layer.csv, USB EC.kicad_sch, analog.kicad_sch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]
2025-05-03 EC 2 layer production files
    [matrix.kicad_sch, mounting holes.kicad_sch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]
2025-05-06 BLE & EC edited
    requires production files!!
    [BOM-pandemonium BLE e7 cutout.csv, USB EC.kicad_sch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]
2025-05-09 jst revision
    fresh production files
    [BOM-pandemonium BLE e7 cutout.csv, BOM-pandemonium EC 2 Layer.csv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]
